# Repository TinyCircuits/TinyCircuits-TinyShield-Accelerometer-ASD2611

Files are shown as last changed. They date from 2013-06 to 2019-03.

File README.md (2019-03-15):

# TinyCircuits TinyShield Accelerometer Board
# ASD2611 Rev1

These are the design files for the TinyCircuits ASD2611 Rev 1 PCB.  This is a TinyShield board (Square Version, 20mm x 20mm, or Circular 20mm diameter) that has a Bosch BMA250 accelerometer, local power supply and level shifters to connect between the TinyDuino and the accelerometer. 

Format is in Cadsoft Eagle format - Eagle version 6.2 was used for the original design.

For more infomation on this, check out the product page at Tiny-Circuits.com:  https://tinycircuits.com/collections/sensors/products/accelerometer-tinyshield 

# License:

Design by TinyCircuits.
All design files are released under the Creative Commons Attribution Share-Alike 3.0 License, see the following link for details: http://creativecommons.org/licenses/by-sa/3.0

All text above must be included in any redistribution or derived design

This project uses designs and concepts developed as part of the Arduino project and the LilyPad project.  The TinyCircuits design files themselves (schematics, PCB and libraries) are not directly derived from these works' design files and have been created new, however the concepts and basic architecture behind the TinyDuino and TinyLily products are derived and we thank the hard work of the organizations below for their contributions to open-source hardware:
  
Original Arduino Uno Design by Team Arduino

LilyPad Arduino Design by Leah Buechley and Sparkfun Electronics

Please support the open-source hardware community

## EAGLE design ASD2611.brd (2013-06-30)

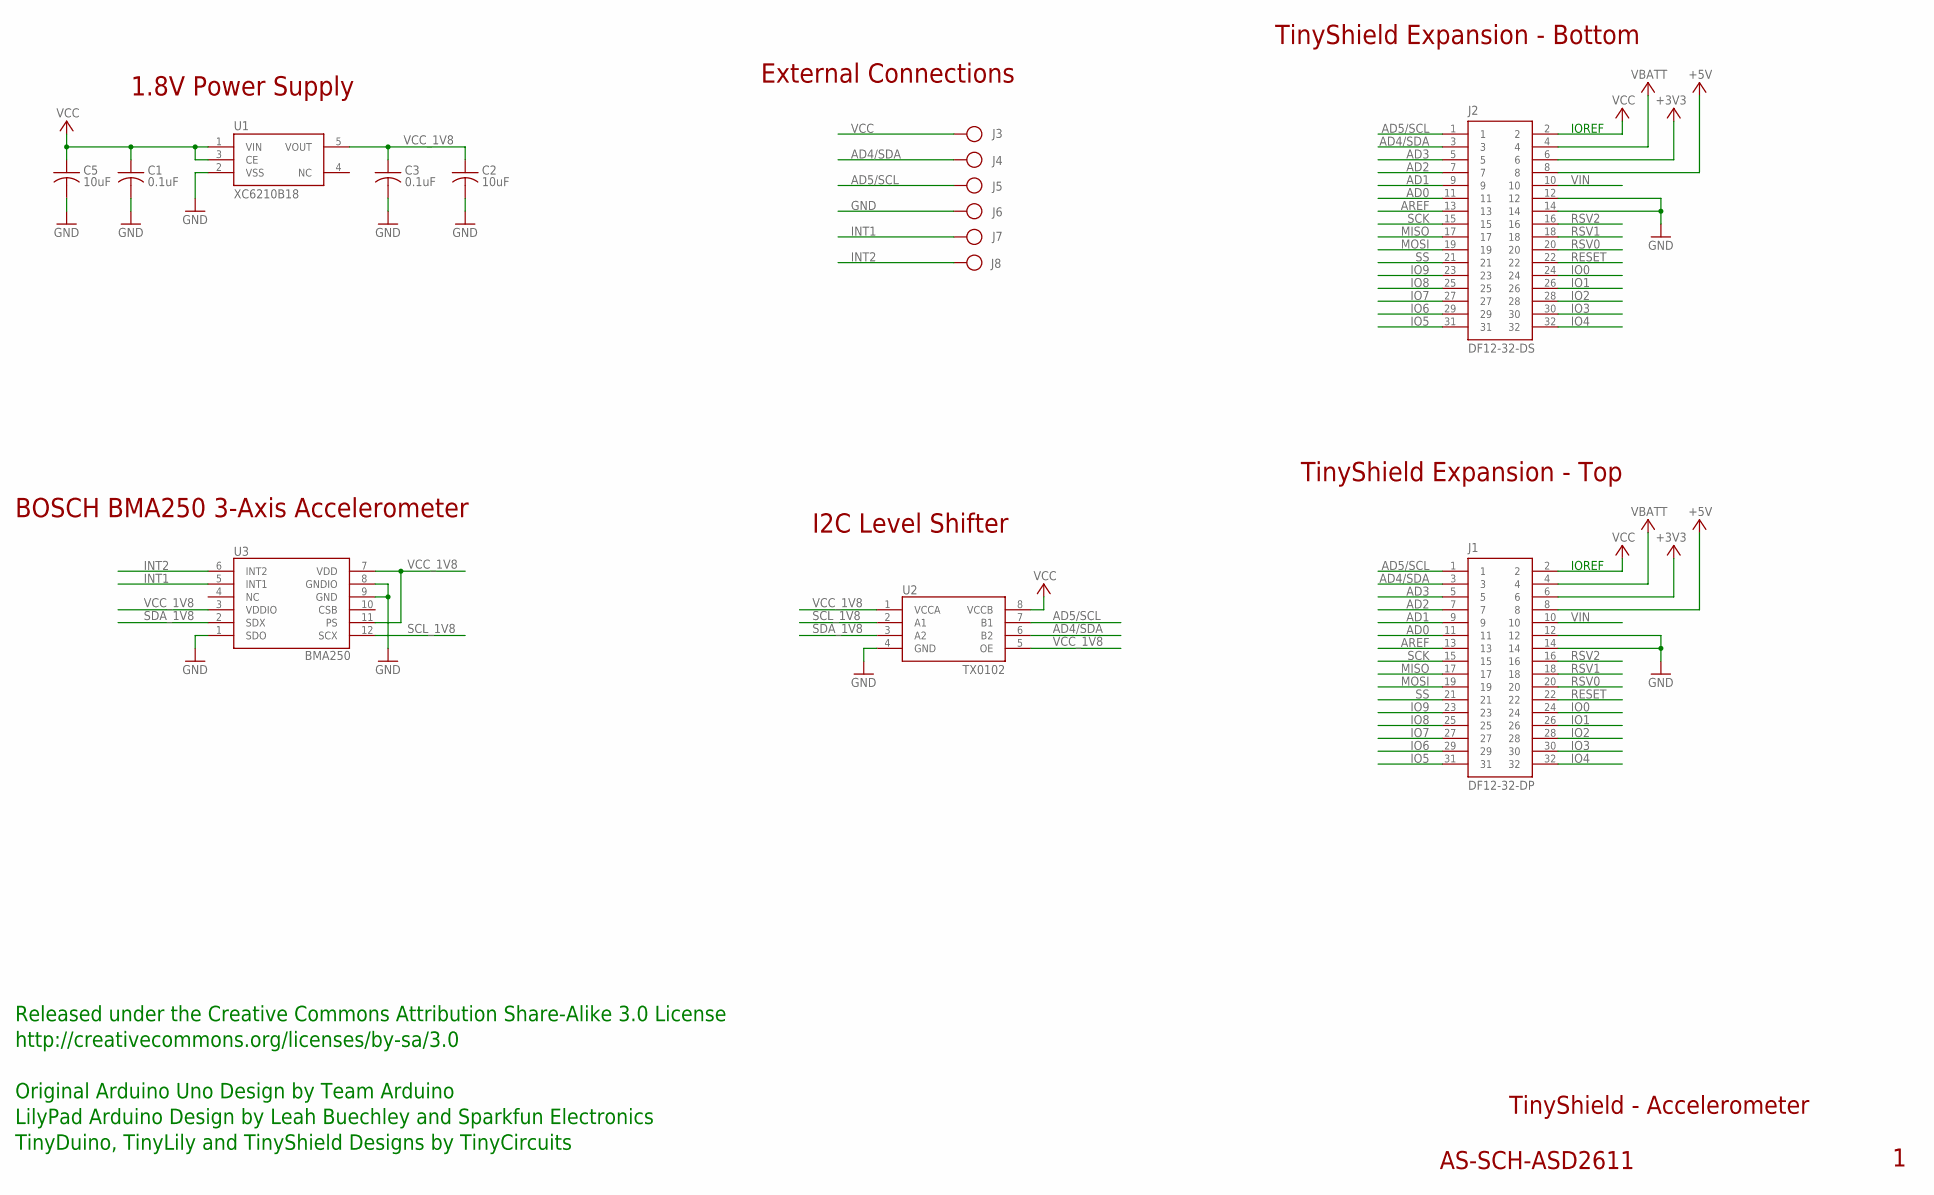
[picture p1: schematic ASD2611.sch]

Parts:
C1, C3: 0.1uF; C0402; PARTNO AS-ITM-00008
C2: 10uF; C0805; PARTNO AS-ITM-00045
C5: 10uF; C0805
J1: DF12-32-DP; PARTNO AS-ITM-00015
J2: DF12-32-DS; PARTNO AS-ITM-00012
J3, J4, J5, J6, J7, J8: PIN_1X.1"; 1X.1"
U1: XC6210B18; SOT-25; PARTNO AS-ITM-00075
U2: TX0102; DQE(R-PX2SON-N8)
U3: BMA250; 3-AXIS_ACCELEROMETER

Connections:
+3V3: J1.6, J2.6
+5V: J1.8, J2.8
AD0: J1.11, J2.11
AD1: J1.9, J2.9
AD2: J1.7, J2.7
AD3: J1.5, J2.5
AD4/SDA: J1.3, J2.3, J4.1, U2.6 (B2)
AD5/SCL: J1.1, J2.1, J5.1, U2.7 (B1)
AREF: J1.13, J2.13
GND: C1.2, C2.2, C3.2, C5.2, J1.12, J1.14, J2.12, J2.14, J6.1, U1.2 (VSS), U2.4 (GND), U3.1 (SDO), U3.8 (GNDIO), U3.9 (GND)
INT1: J7.1, U3.5 (INT1)
INT2: J8.1, U3.6 (INT2)
IO0: J1.24, J2.24
IO1: J1.26, J2.26
IO2: J1.28, J2.28
IO3: J1.30, J2.30
IO4: J1.32, J2.32
IO5: J1.31, J2.31
IO6: J1.29, J2.29
IO7: J1.27, J2.27
IO8: J1.25, J2.25
IO9: J1.23, J2.23
MISO: J1.17, J2.17
MOSI: J1.19, J2.19
RESET: J1.22, J2.22
RSV0: J1.20, J2.20
RSV1: J1.18, J2.18
RSV2: J1.16, J2.16
SCK: J1.15, J2.15
SCL_1V8: U2.2 (A1), U3.12 (SCX)
SDA_1V8: U2.3 (A2), U3.2 (SDX)
SS: J1.21, J2.21
VBATT: J1.4, J2.4
VCC: C1.1, C5.1, J1.2, J2.2, J3.1, U1.1 (VIN), U1.3 (CE), U2.8 (VCCB)
VCC_1V8: C2.1, C3.1, U1.5 (VOUT), U2.1 (VCCA), U2.5 (OE), U3.3 (VDDIO), U3.7 (VDD), U3.11 (PS)
VIN: J1.10, J2.10

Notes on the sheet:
TinyShield Expansion - Bottom
TinyShield - Accelerometer
AS-SCH-ASD2611
TinyShield Expansion - Top
IOREF
Released under the Creative Commons Attribution Share-Alike 3.0 License
http://creativecommons.org/licenses/by-sa/3.0
LilyPad Arduino Design by Leah Buechley and Sparkfun Electronics
TinyDuino, TinyLily and TinyShield Designs by TinyCircuits
Original Arduino Uno Design by Team Arduino
External Connections
1.8V Power Supply
I2C Level Shifter
BOSCH BMA250 3-Axis Accelerometer

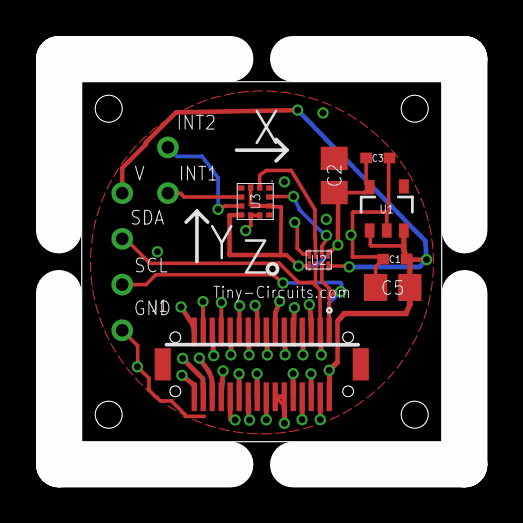
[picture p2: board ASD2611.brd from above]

Board: 2 copper layers, 20.0 x 20.0 mm, 16 parts (1 on the bottom side), 36 nets.

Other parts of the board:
U$1: DOCFIELD-TINYCIRCUITS-PCB

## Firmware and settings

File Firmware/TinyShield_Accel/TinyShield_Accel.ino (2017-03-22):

/*
TinyDuino Accelerometer Demo
  
Updated 15 August 2016 to use the correct serial monitor interface for
TinyDuino or TinyScreen+

This example code is in the public domain.

http://www.tinycircuits.com

*/


#include <Wire.h>
#include "BMA250.h"


#if defined(ARDUINO_ARCH_SAMD)
#define SerialMonitorInterface SerialUSB
#else
#define SerialMonitorInterface Serial
#endif

BMA250 accel;


void setup()
{
  SerialMonitorInterface.begin(9600);
  Wire.begin();
  accel.begin(BMA250_range_2g, BMA250_update_time_64ms);//This sets up the BMA250 accelerometer
}

void loop()
{
  accel.read();//This function gets new data from the accelerometer
  SerialMonitorInterface.print("X = ");
  SerialMonitorInterface.print(accel.X);
  SerialMonitorInterface.print("  ");
  SerialMonitorInterface.print("Y = ");
  SerialMonitorInterface.print(accel.Y);
  SerialMonitorInterface.print("  ");
  SerialMonitorInterface.print("Z = ");
  SerialMonitorInterface.print(accel.Z);
  SerialMonitorInterface.print("  Temperature(C) = ");
  SerialMonitorInterface.println((accel.rawTemp*0.5)+24.0,1);
  delay(250);//We'll make sure we're over the 64ms update time set on the BMA250
}
